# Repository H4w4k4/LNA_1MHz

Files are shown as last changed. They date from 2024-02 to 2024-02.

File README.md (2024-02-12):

 # LNA_1MHz
10Hz to 1MHz Low Noise Amplifier based on Linear Technology AN-159.

<p align="center">

 &nbsp; &nbsp;


</p>

# Design
The design is based on [Linear Technology AN-159 document](https://www.analog.com/en/resources/app-notes/an-159.html#author). It describe how to build a +80dB 10Hz to 1MHz low noise amplifier in order to measure noise level in the 2nV/√Hz range.

Following changes have been done:
+ Design re-routed in KiCad 7.0 to fit nicely into a Hammond 1590BBS housing
+ Selectable +60dB or +80dB gain
+ Full BW output removed

# Measure
A 60dB attenuator is placed on the input of the LNA to measure the frequency response. An Analog Discovery 3 is used as a network analyser.

<p align="center">

</p>

# Building it
The complete production files are available. The PCB is a 4-layer 102 x 82.6mm and every components is hand solderable. The LNA is powered by 6x AA batteries, consumption is about 100mA. Use the Gerber "housing_Lid_Drill" for drilling the holes in the housing cover. 

Total BOM cost is ~160USD + PCB + shipping.

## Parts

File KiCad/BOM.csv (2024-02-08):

Reference | Value | Footprint | Datasheet | Part | Qté
C1-C3, C6-C11, C13 | 68uF 20V | Capacitor_Tantalum_SMD:CP_EIA-7343-30_AVX-N_Pad2.25x2.55mm_HandSolder | ~ | AVX, TPSE686M020R0150 | 10
C4, C5 | 4u7F 50V | Capacitor_THT:C_Rect_L7.2mm_W7.2mm_P5.00mm_FKS2_FKP2_MKS2_MKP2 | ~ | WIMA, MKS2B044701K00K | 2
C12 | 150pF | Capacitor_SMD:C_1206_3216Metric_Pad1.33x1.80mm_HandSolder | ~ | AVX, 12065A151JAT2A | 1
C14 | 120pF | Capacitor_SMD:C_1206_3216Metric_Pad1.33x1.80mm_HandSolder | ~ | AVX, 12065A121JAT2A | 1
C15-C17, C19-C22, C24, C25, C28, C29, C32-C34 | 100uF 6V3 | Capacitor_SMD:C_1206_3216Metric_Pad1.33x1.80mm_HandSolder | ~ | MURATA, GRM31CR60J107ME39L | 14
C18, C39, C44, C49, C54 | 22pF | Capacitor_SMD:C_1206_3216Metric_Pad1.33x1.80mm_HandSolder | ~ | AVX, 12065A220JAT2A | 5
C23 | 100pF | Capacitor_SMD:C_1206_3216Metric_Pad1.33x1.80mm_HandSolder | ~ | AVX, 12065A101JAT2A | 1
C26 | 1500pF | Capacitor_SMD:C_1206_3216Metric_Pad1.33x1.80mm_HandSolder | ~ | AVX, 12065A152JAT2A | 1
C27 | 1200pF | Capacitor_SMD:C_1206_3216Metric_Pad1.33x1.80mm_HandSolder | ~ | AVX, 12065A122JAT2A | 1
C30 | 220pF | Capacitor_SMD:C_1206_3216Metric_Pad1.33x1.80mm_HandSolder | ~ | AVX, 12065A221JAT2A | 1
C31 | 1000pF | Capacitor_SMD:C_1206_3216Metric_Pad1.33x1.80mm_HandSolder | ~ | AVX, 12065A102JAT2A | 1
C35-C38, C42, C43, C47, C48, C52, C53, C57, C58 | 1uF | Capacitor_THT:C_Rect_L7.2mm_W5.5mm_P5.00mm_FKS2_FKP2_MKS2_MKP2 | ~ | WIMA, MKS2C041001F00K | 12
C40, C45, C50, C55 | 330uF 6V3 | Capacitor_Tantalum_SMD:CP_EIA-7343-30_AVX-N_Pad2.25x2.55mm_HandSolder | ~ | AVX, TPSD337M006R0100 | 4
C41, C46, C51, C56 | 300pF | Capacitor_SMD:C_0805_2012Metric_Pad1.18x1.45mm_HandSolder | ~ | AVX, 08053C301JAT2A | 4
C59, C60 | 180uF 25V | Capacitor_THT:CP_Radial_D8.0mm_P3.50mm | ~ | PANASONIC, 25SEPF180M | 2
H1-H6 | ~ | TestPoint:TestPoint_THTPad_2.0x2.0mm_Drill1.0mm | ~ |  | 6
J1-J3 | Conn_Coaxial | User_footprint:BNC_TycoElect_5227 | ~ | -- valeurs mixtées -- | 3
M1 | Hammond_1590BBS | User_footprint:Hammond_1590BBS |  | Hammond, 1590BBS | 1
M2, M3 | Battery_3x_AA | User_footprint:Battery_Holder_3x_AA_no_pin |  | Multicomp, MP000331 | 2
M4 | Switch DPDT | User_footprint:Multicomp, 1MD1T1B5M1QE |  | Multicomp, 1MD1T1B5M1QE | 1
M5 | Switch SPDT | User_footprint:Multicomp, 1MS1T1B5M1QE |  | Multicomp, 1MS1T1B5M1QE | 1
R1 | 1k5 | Resistor_SMD:R_1206_3216Metric_Pad1.30x1.75mm_HandSolder | ~ | VISHAY, CRCW12061K50FKEA | 1
R2 | 511 | Resistor_SMD:R_1206_3216Metric_Pad1.30x1.75mm_HandSolder | ~ | VISHAY, CRCW1206511RFKEA | 1
R3, R5-R7, R9, R10 | 100 | Resistor_SMD:R_1206_3216Metric_Pad1.30x1.75mm_HandSolder | ~ | VISHAY, CRCW1206100RFKEA | 6
R4 | 2k | Resistor_SMD:R_1206_3216Metric_Pad1.30x1.75mm_HandSolder | ~ | VISHAY, CRCW12062K00FKEA | 1
R8 | 5k76 | Resistor_SMD:R_1206_3216Metric_Pad1.30x1.75mm_HandSolder | ~ | VISHAY, CRCW12065K76FKEA | 1
R11 | 499 | Resistor_SMD:R_1206_3216Metric_Pad1.30x1.75mm_HandSolder | ~ | VISHAY, CRCW1206499RFKEA | 1
R12, R17, R22, R23, R27, R28, R30, R31, R35, R36, R38, R39, R43, R44, R46, R47, R51, R52 | 4k02 | Resistor_SMD:R_1206_3216Metric_Pad1.30x1.75mm_HandSolder | ~ | VISHAY, CRCW12064K02FKEA | 18
R13, R18 | 2k15 | Resistor_SMD:R_1206_3216Metric_Pad1.30x1.75mm_HandSolder | ~ | VISHAY, CRCW12062K15FKEA | 2
R14, R19 | 1k69 | Resistor_SMD:R_1206_3216Metric_Pad1.30x1.75mm_HandSolder | ~ | VISHAY, CRCW12061K69FKEA | 2
R15, R20 | 1k24 | Resistor_SMD:R_1206_3216Metric_Pad1.30x1.75mm_HandSolder | ~ | VISHAY, CRCW12061K24FKEA | 2
R16, R21 | 49R9 | Resistor_SMD:R_1206_3216Metric_Pad1.30x1.75mm_HandSolder | ~ | VISHAY, CRCW120649R9FKEA | 2
R24, R25, R32, R33, R40, R41, R48, R49 | 499 | Resistor_SMD:R_0805_2012Metric_Pad1.20x1.40mm_HandSolder | ~ | VISHAY, CRCW0805499RFKEA | 8
R26, R34, R42, R50 | 249 | Resistor_SMD:R_1206_3216Metric_Pad1.30x1.75mm_HandSolder | ~ | YAGEO, RC1206FR-07249RL | 4
R29, R37, R45, R53 | 10 | Resistor_SMD:R_1206_3216Metric_Pad1.30x1.75mm_HandSolder | ~ | VISHAY, CRCW120610R0FKEAC | 4
RV1 | 1k | Potentiometer_THT:Potentiometer_Bourns_3296X_Horizontal | ~ | BOURNS, 3296X-1-102LF | 1
RV2 | 200 | Potentiometer_THT:Potentiometer_Bourns_3296X_Horizontal | ~ | BOURNS, 3296X-1-201LF | 1
U1 | LT6232CGN | Package_SO:SSOP-16_3.9x4.9mm_P0.635mm | https://www.analog.com/media/en/technical-documentation/data-sheets/623012fc.pdf | Linear Tech., LT6232CGN#PBF | 1
U2 | LT1365CS | Package_SO:SO-16_3.9x9.9mm_P1.27mm | https://www.analog.com/media/en/technical-documentation/data-sheets/13645fa.pdf | Linear Tech., LT1365CS#PBF | 1
U3, U5, U7, U9 | LT1818CS8 | Package_SO:SO-8_3.9x4.9mm_P1.27mm | https://www.analog.com/media/en/technical-documentation/data-sheets/18189fb.pdf | Linear Tech., LT1818CS8#PBF | 4
U4, U6, U8, U10 | THAT300S14-U | Package_SO:SOIC-14_3.9x8.7mm_P1.27mm |  | THAT Corporation, THAT300S14-U | 4

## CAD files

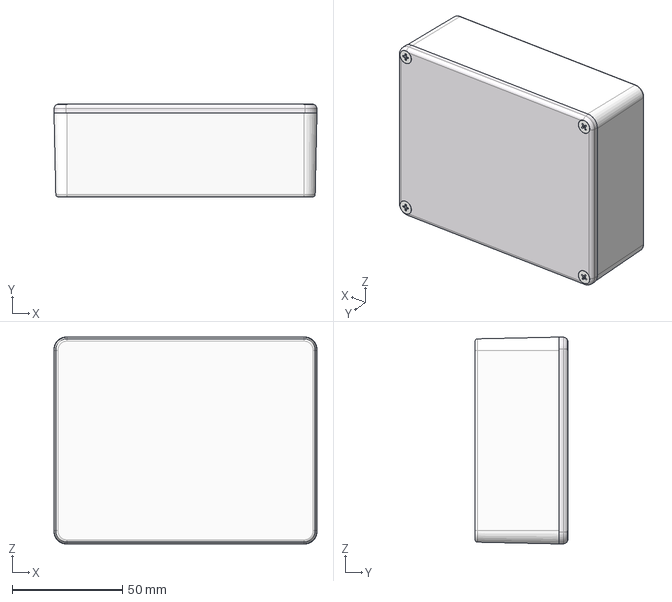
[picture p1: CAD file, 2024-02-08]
Datasheet/1590BBS.stp
119.5 x 42.1 x 94.0 mm
1590BBS BOX
1590C LID

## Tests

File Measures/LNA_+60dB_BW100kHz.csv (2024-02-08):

#Digilent WaveForms Network Analyzer - Bode
#Device Name: Discovery3
#Date Time: 2024-02-08 18:55:14.613
#Start: 1 Hz
#Stop: 2e+06 Hz
#Steps: 151
#Wavegen: Wavegen C1
#Amplification: 1 X
#Settle: 10 ms
#MinPeriods: 32
#Channel: Channel 2
#Range: 5.13569 V
#Offset: 8.29643e-05 V
#Relative: yes
Frequency (Hz) | Channel 2 Magnitude (dB) | Channel 2 Phase (deg)
1.000000000000002 | -69.21915246975358 | -10.53627862849748
1.101556726136675 | -65.77347539883461 | -15.40823207395555
1.213427220896945 | -62.46739881671027 | -19.32897107968216
1.336658916856357 | -59.15304754669258 | -24.49056377111295
1.472405620413677 | -55.86433923501731 | -29.5831362070994
1.621938314768127 | -52.57366210205483 | -34.94621980450103
1.786657060011607 | -49.28892850285725 | -40.45000866842491
1.968104101755354 | -46.04095129571814 | -46.43900398095219
2.167978311025786 | -42.79188704663309 | -52.81104147129451
2.388151090628878 | -39.58508847265773 | -59.62683612144482
2.630683896912867 | -36.40459607019136 | -66.90852757420174
2.897847540983796 | -33.26233210588731 | -74.70068064957806
3.192143450089312 | -30.18728147217772 | -82.99532355520429
3.516327088239006 | -27.19509883693937 | -91.79747261116199
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

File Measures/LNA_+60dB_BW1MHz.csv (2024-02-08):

#Digilent WaveForms Network Analyzer - Bode
#Device Name: Discovery3
#Date Time: 2024-02-08 18:37:19.417
#Start: 1 Hz
#Stop: 2e+06 Hz
#Steps: 151
#Wavegen: Wavegen C1
#Amplification: 1 X
#Settle: 10 ms
#MinPeriods: 32
#Channel: Channel 2
#Range: 5.13569 V
#Offset: 8.29643e-05 V
#Relative: yes
Frequency (Hz) | Channel 2 Magnitude (dB) | Channel 2 Phase (deg)
1.000000000000002 | -69.04775908654929 | -10.72955637263085
1.101556726136675 | -65.82871182051774 | -15.40263981909862
1.213427220896945 | -62.47151987370549 | -20.08651417017764
1.336658916856357 | -59.13202901519229 | -24.67357037469868
1.472405620413677 | -55.85419452960114 | -29.75647817102871
1.621938314768127 | -52.56066100462618 | -35.11122578529563
1.786657060011607 | -49.27228953772921 | -40.69510331111118
1.968104101755354 | -45.9244819256 | -46.72983689252341
2.167978311025786 | -42.6936882901208 | -53.10627089097253
2.388151090628878 | -39.49241014424292 | -59.91638837230778
2.630683896912867 | -36.31540838655298 | -67.2299170460977
2.897847540983796 | -33.18452881246163 | -75.01662364643897
3.192143450089312 | -30.11804440064484 | -83.31408385802631
3.516327088239006 | -27.13069815361774 | -92.11605199372303
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

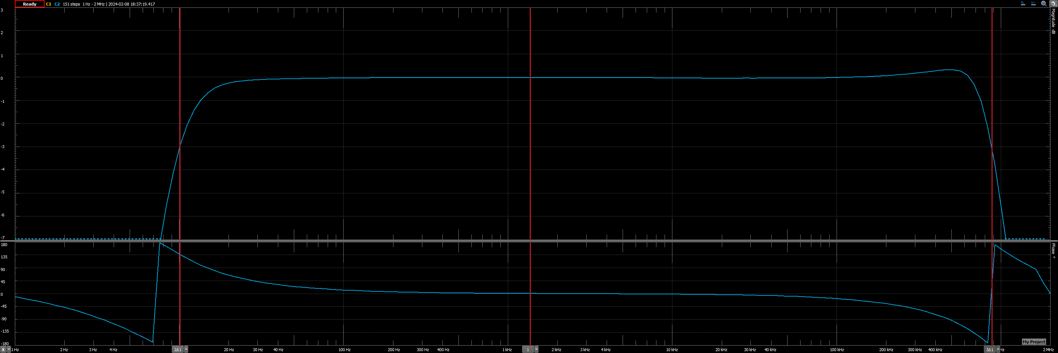
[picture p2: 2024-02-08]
Measures/LNA_+60dB_BW1MHz.png

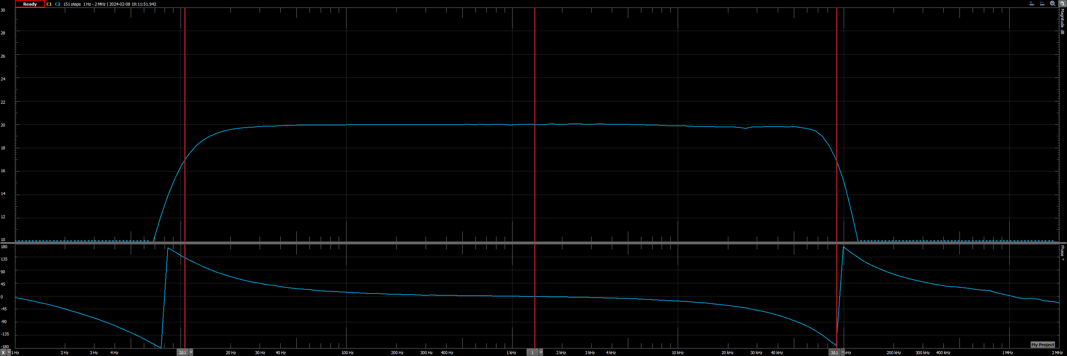
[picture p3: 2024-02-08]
Measures/LNA_+80dB_BW100kHz.png

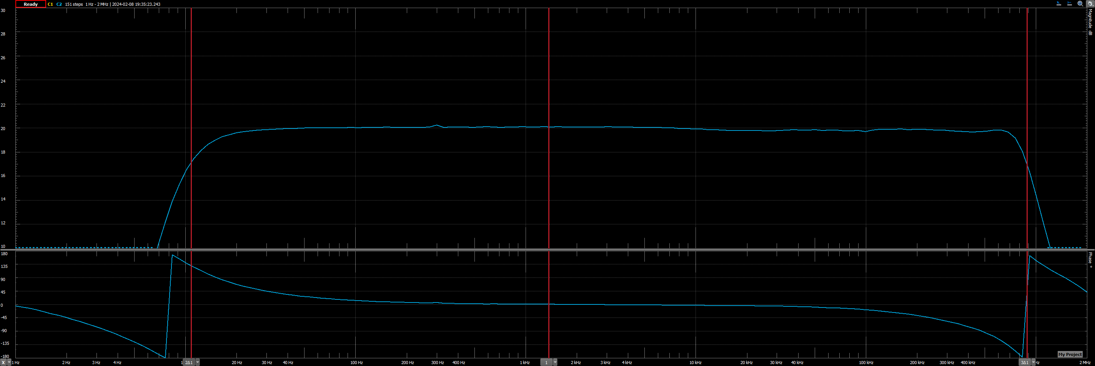
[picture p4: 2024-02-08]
Measures/LNA_+80dB_BW1MHz.png

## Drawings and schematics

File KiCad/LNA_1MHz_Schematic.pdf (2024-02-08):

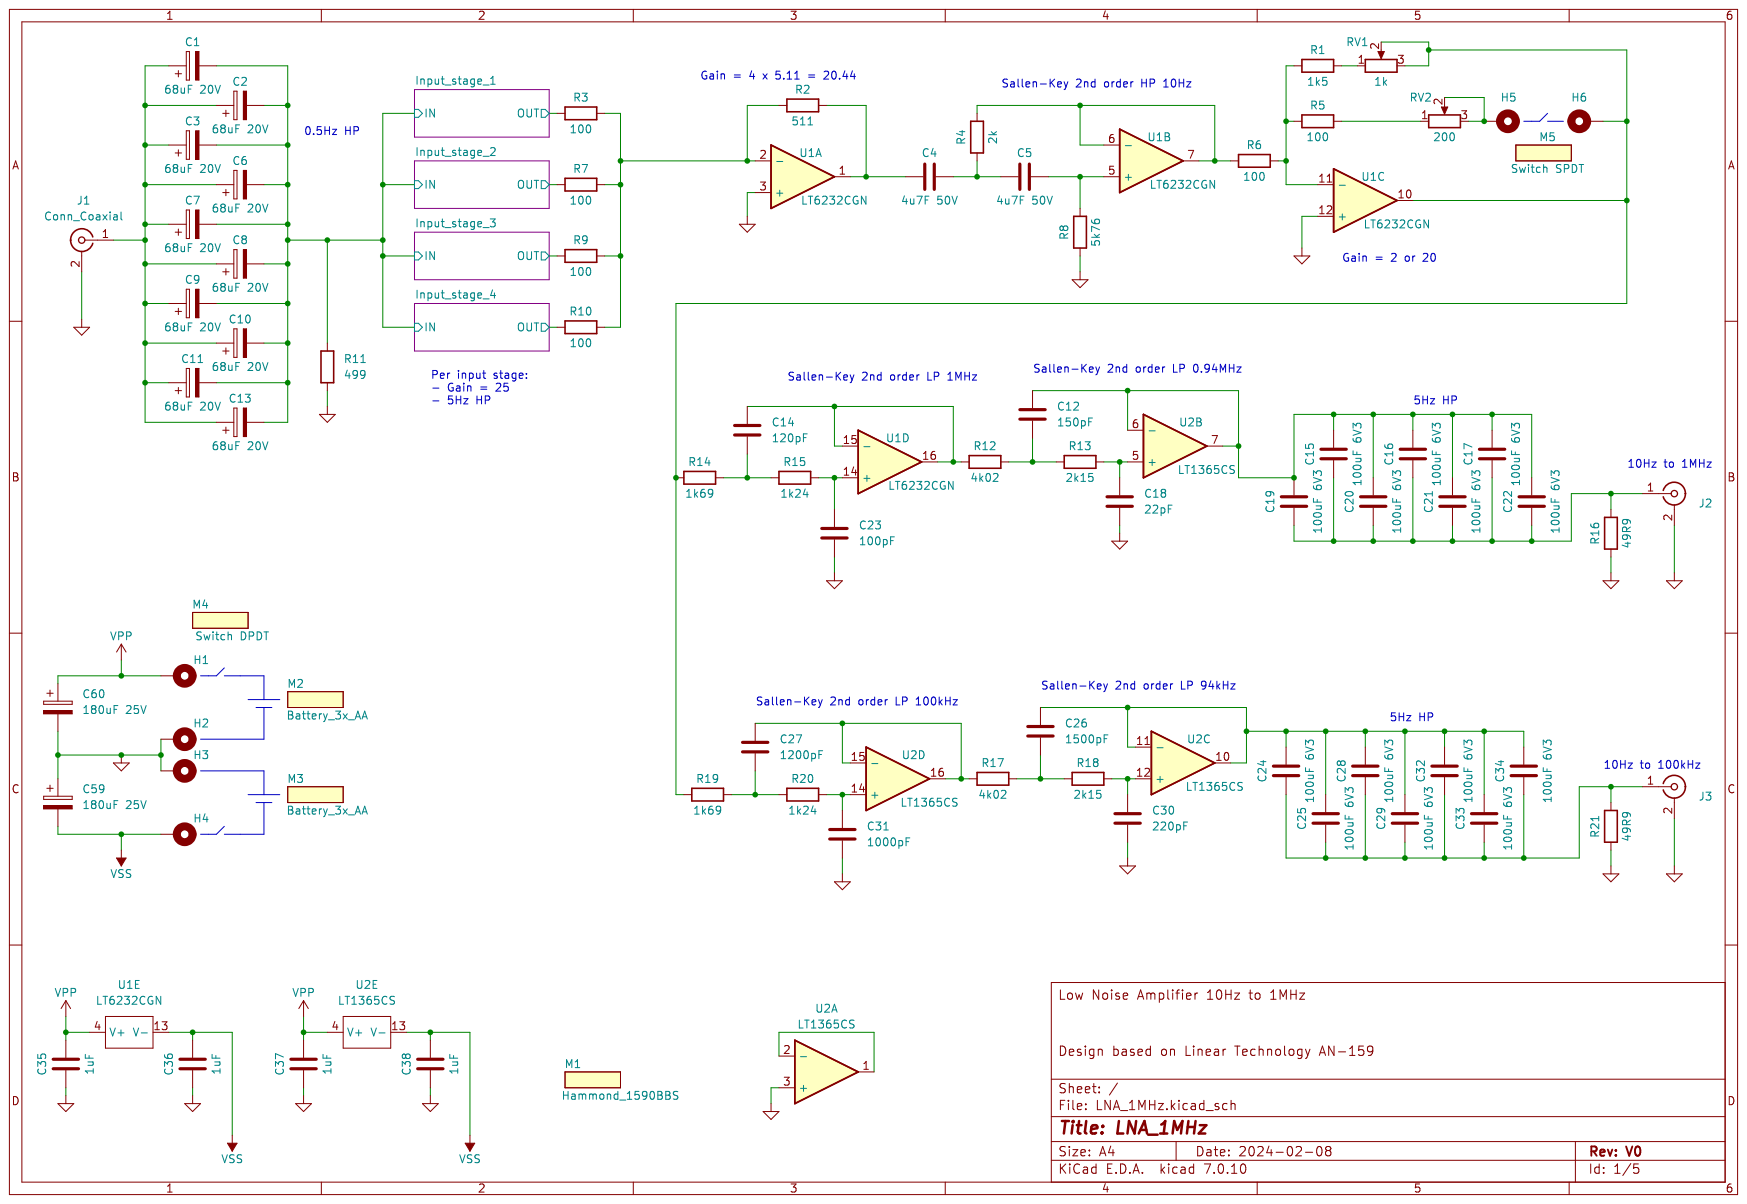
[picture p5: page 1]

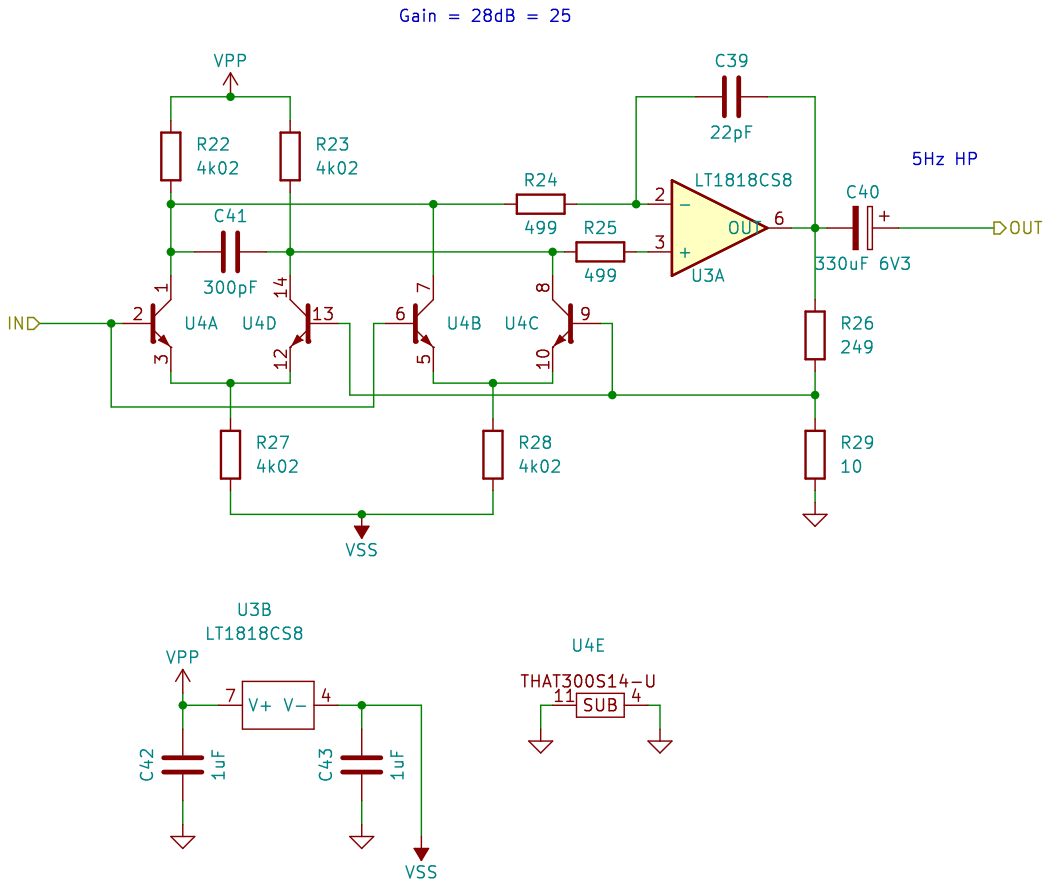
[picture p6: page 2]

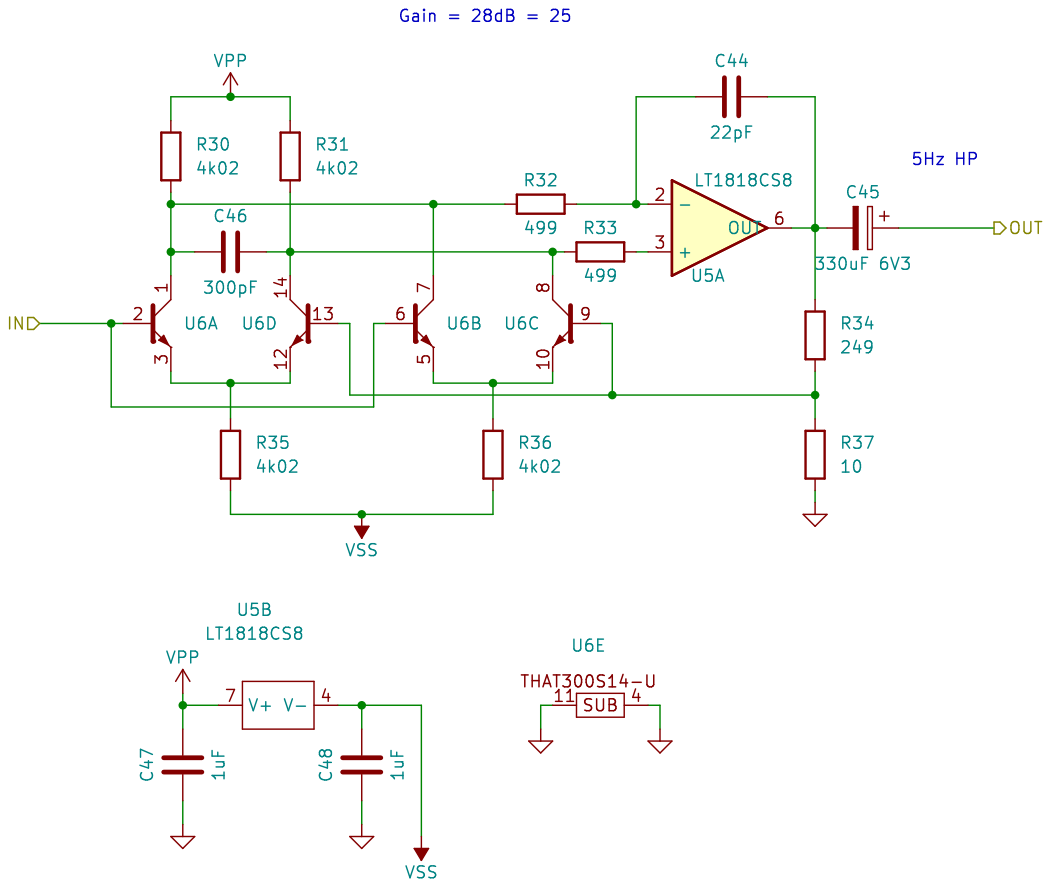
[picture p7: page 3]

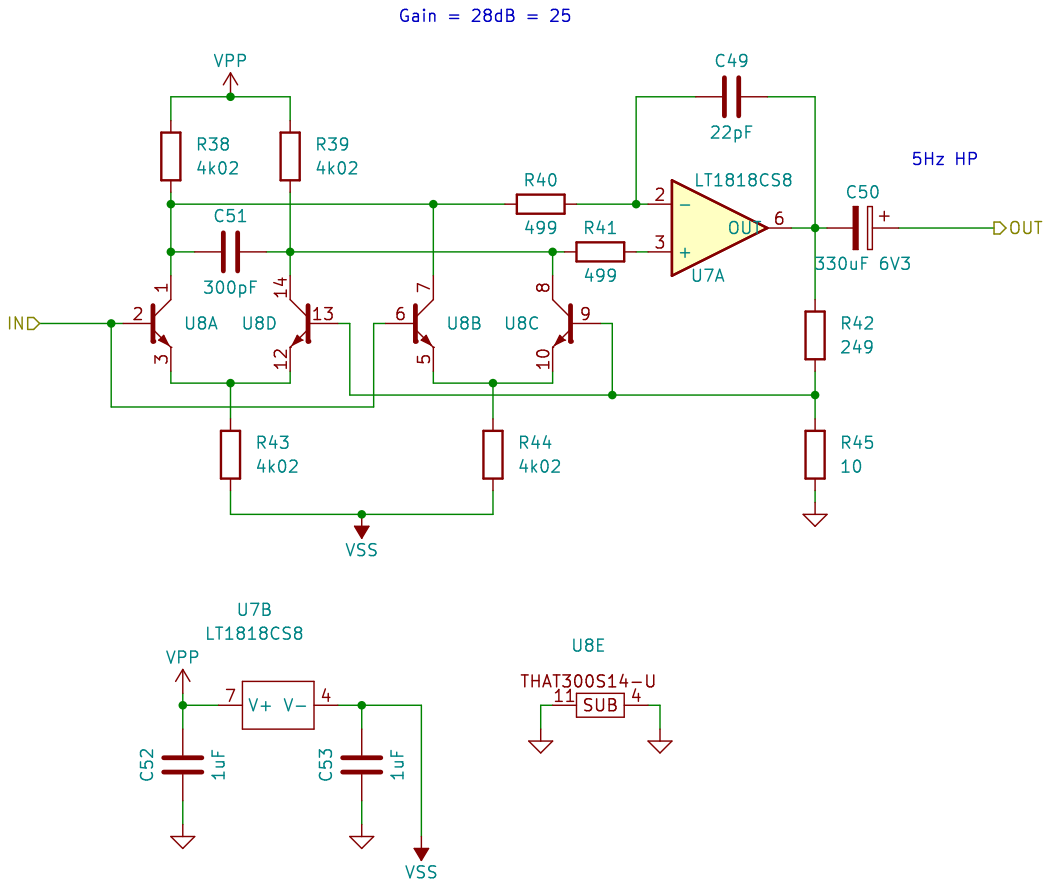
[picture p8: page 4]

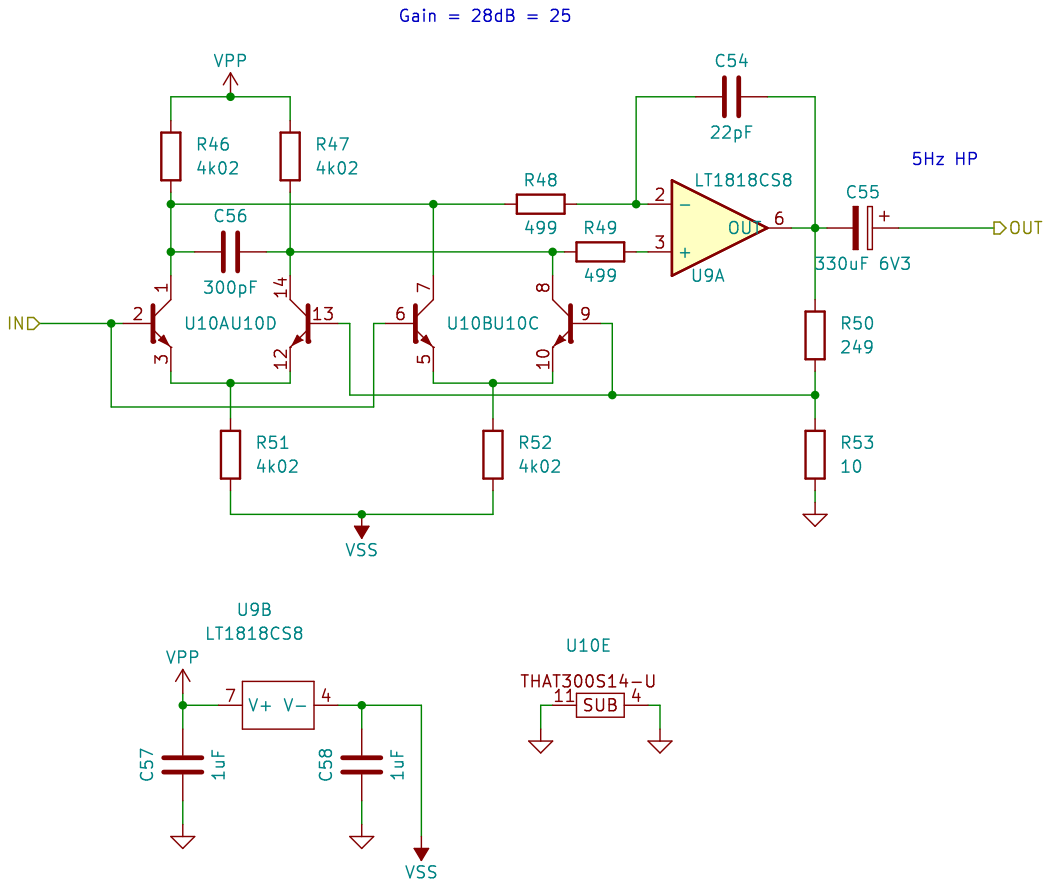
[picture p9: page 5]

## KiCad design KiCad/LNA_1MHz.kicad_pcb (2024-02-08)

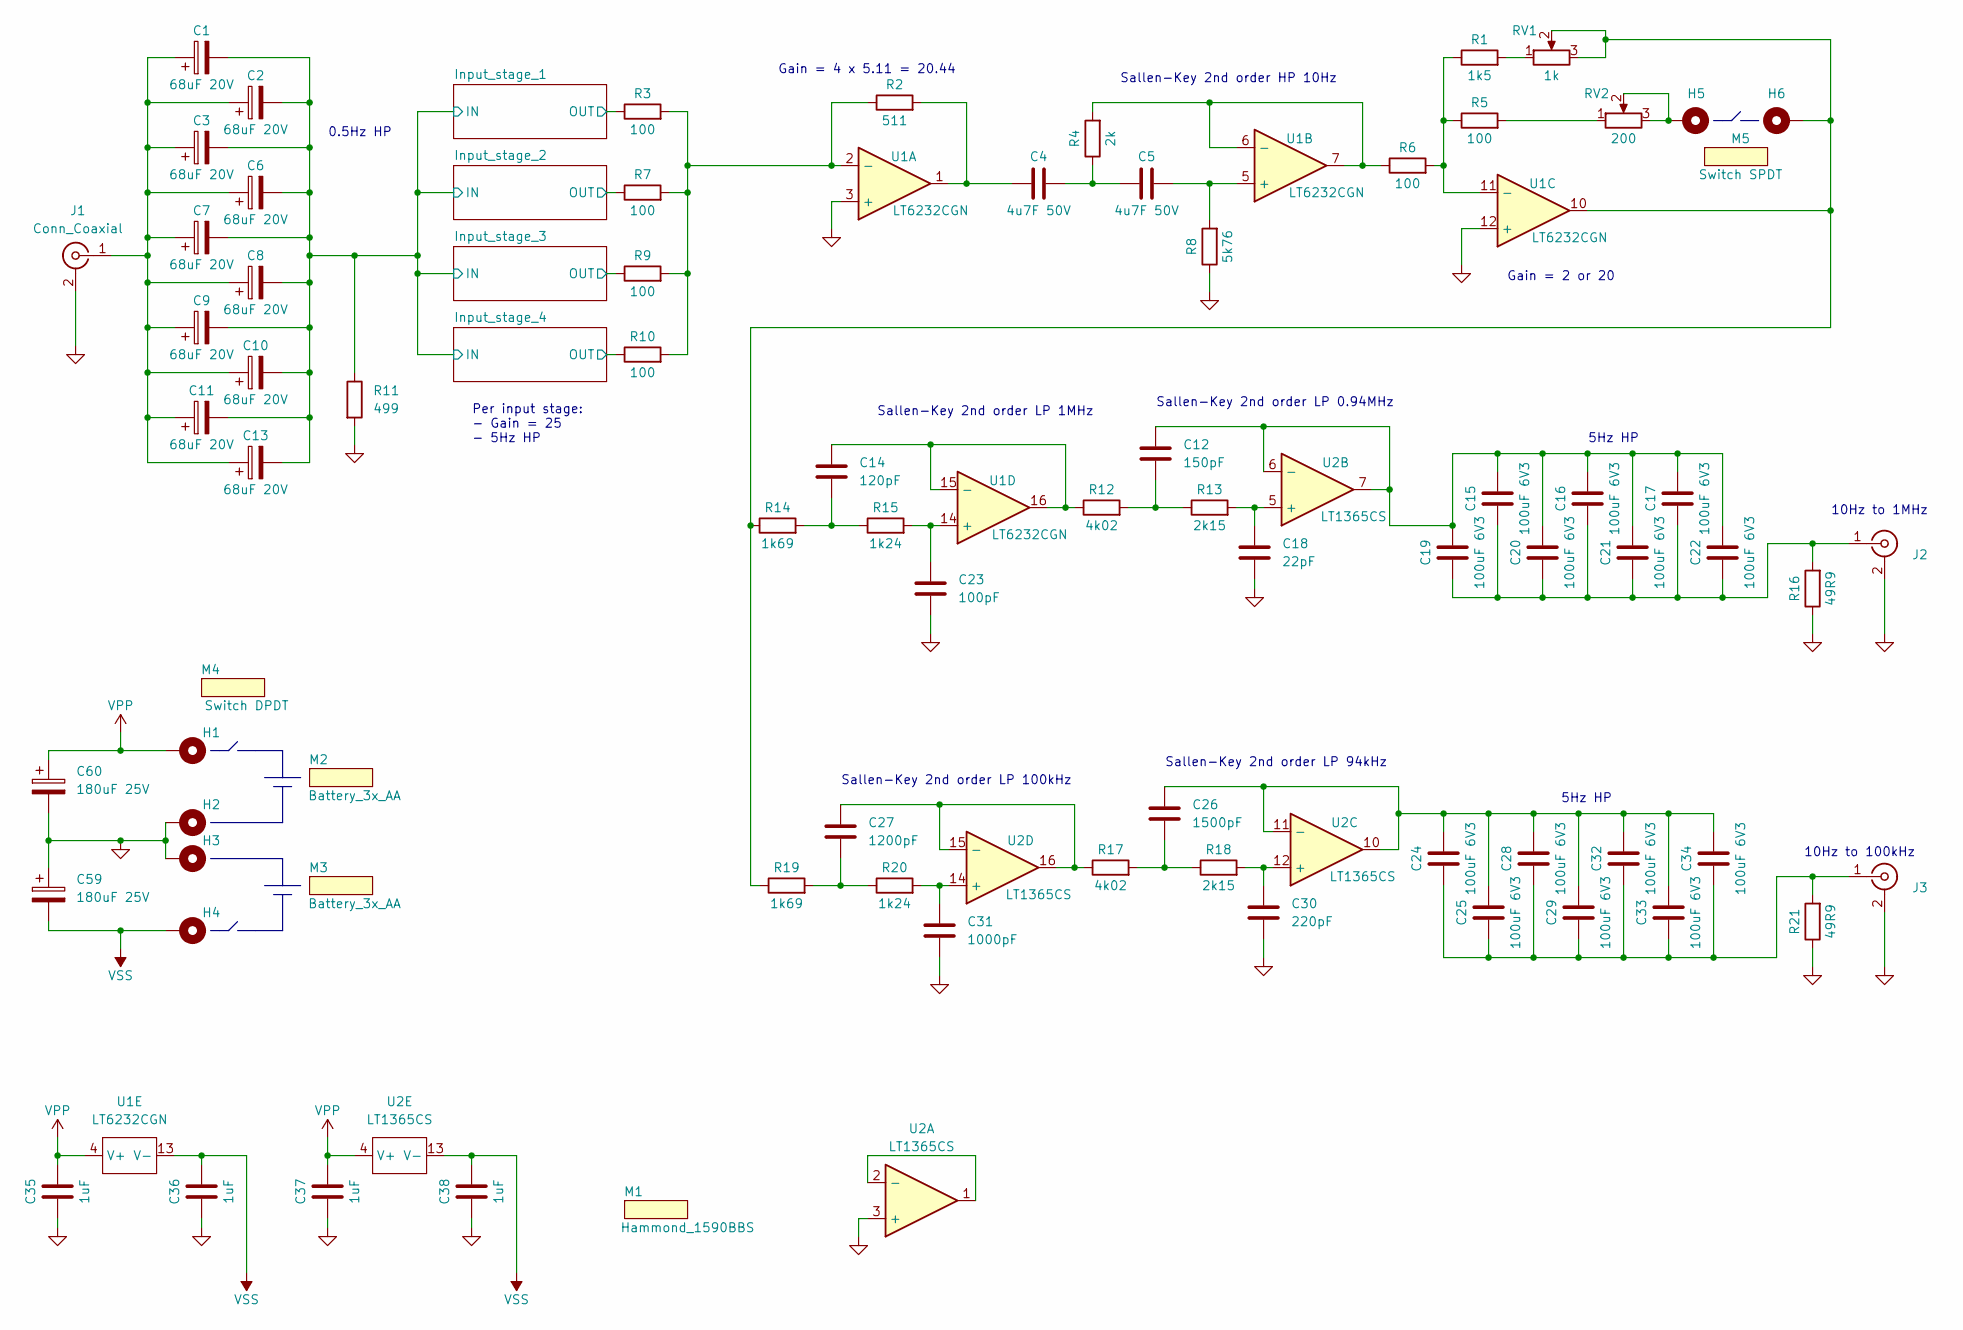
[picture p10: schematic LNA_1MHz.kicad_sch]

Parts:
C1, C2, C3, C6, C7, C8, C9, C10, C11, C13: 68uF 20V; CP_EIA-7343-30_AVX-N_Pad2.25x2.55mm_HandSolder; Part AVX, TPSE686M020R0150
C4, C5: 4u7F 50V; C_Rect_L7.2mm_W7.2mm_P5.00mm_FKS2_FKP2_MKS2_MKP2; Part WIMA, MKS2B044701K00K
C12: 150pF; C_1206_3216Metric_Pad1.33x1.80mm_HandSolder; Part AVX, 12065A151JAT2A
C14: 120pF; C_1206_3216Metric_Pad1.33x1.80mm_HandSolder; Part AVX, 12065A121JAT2A
C15, C16, C17, C19, C20, C21, C22, C24, C25, C28, C29, C32, C33, C34: 100uF 6V3; C_1206_3216Metric_Pad1.33x1.80mm_HandSolder; Part MURATA, GRM31CR60J107ME39L
C18: 22pF; C_1206_3216Metric_Pad1.33x1.80mm_HandSolder; Part AVX, 12065A220JAT2A
C23: 100pF; C_1206_3216Metric_Pad1.33x1.80mm_HandSolder; Part AVX, 12065A101JAT2A
C26: 1500pF; C_1206_3216Metric_Pad1.33x1.80mm_HandSolder; Part AVX, 12065A152JAT2A
C27: 1200pF; C_1206_3216Metric_Pad1.33x1.80mm_HandSolder; Part AVX, 12065A122JAT2A
C30: 220pF; C_1206_3216Metric_Pad1.33x1.80mm_HandSolder; Part AVX, 12065A221JAT2A
C31: 1000pF; C_1206_3216Metric_Pad1.33x1.80mm_HandSolder; Part AVX, 12065A102JAT2A
C35, C36, C37, C38: 1uF; C_Rect_L7.2mm_W5.5mm_P5.00mm_FKS2_FKP2_MKS2_MKP2; Part WIMA, MKS2C041001F00K
C59, C60: 180uF 25V; CP_Radial_D8.0mm_P3.50mm; Part PANASONIC, 25SEPF180M
H1, H2, H3, H4, H5, H6: TestPoint_THTPad_2.0x2.0mm_Drill1.0mm
J1: Conn_Coaxial; BNC_TycoElect_5227; Part TE 5227673­1, TE 1­329632­2, TE 1­32963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
J2, J3: Conn_Coaxial; BNC_TycoElect_5227; Part TE 5227222-3, TE 1­329632­2, TE 1­32963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
M1: Hammond_1590BBS; Part Hammond, 1590BBS
M2, M3: Battery_3x_AA; Battery_Holder_3x_AA_no_pin; Part Multicomp, MP000331
M4: Switch DPDT; Multicomp, 1MD1T1B5M1QE; Part Multicomp, 1MD1T1B5M1QE
M5: Switch SPDT; Multicomp, 1MS1T1B5M1QE; Part Multicomp, 1MS1T1B5M1QE
R1: 1k5; R_1206_3216Metric_Pad1.30x1.75mm_HandSolder; Part VISHAY, CRCW12061K50FKEA
R2: 511; R_1206_3216Metric_Pad1.30x1.75mm_HandSolder; Part VISHAY, CRCW1206511RFKEA
R3, R5, R6, R7, R9, R10: 100; R_1206_3216Metric_Pad1.30x1.75mm_HandSolder; Part VISHAY, CRCW1206100RFKEA
R4: 2k; R_1206_3216Metric_Pad1.30x1.75mm_HandSolder; Part VISHAY, CRCW12062K00FKEA
R8: 5k76; R_1206_3216Metric_Pad1.30x1.75mm_HandSolder; Part VISHAY, CRCW12065K76FKEA
R11: 499; R_1206_3216Metric_Pad1.30x1.75mm_HandSolder; Part VISHAY, CRCW1206499RFKEA
R12, R17: 4k02; R_1206_3216Metric_Pad1.30x1.75mm_HandSolder; Part VISHAY, CRCW12064K02FKEA
R13, R18: 2k15; R_1206_3216Metric_Pad1.30x1.75mm_HandSolder; Part VISHAY, CRCW12062K15FKEA
R14, R19: 1k69; R_1206_3216Metric_Pad1.30x1.75mm_HandSolder; Part VISHAY, CRCW12061K69FKEA
R15, R20: 1k24; R_1206_3216Metric_Pad1.30x1.75mm_HandSolder; Part VISHAY, CRCW12061K24FKEA
R16, R21: 49R9; R_1206_3216Metric_Pad1.30x1.75mm_HandSolder; Part VISHAY, CRCW120649R9FKEA
RV1: 1k; Potentiometer_Bourns_3296X_Horizontal; Part BOURNS, 3296X-1-102LF
RV2: 200; Potentiometer_Bourns_3296X_Horizontal; Part BOURNS, 3296X-1-201LF
U1: LT6232CGN; SSOP-16_3.9x4.9mm_P0.635mm; Part Linear Tech., LT6232CGN#PBF
U2: LT1365CS; SO-16_3.9x9.9mm_P1.27mm; Part Linear Tech., LT1365CS#PBF

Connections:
/Input_stage_1/IN: C1.2, C2.2, C3.2, C6.2, C7.2, C8.2, C9.2, C10.2, C11.2, C13.2, R11.1; also elsewhere on the board
/Input_stage_1/OUT: R3.1; also elsewhere on the board
/Input_stage_2/OUT: R7.1; also elsewhere on the board
/Input_stage_3/OUT: R9.1; also elsewhere on the board
/Input_stage_4/OUT: R10.1; also elsewhere on the board
GND: C18.2, C23.2, C30.2, C31.2, C35.1, C36.1, C37.1, C38.1, C59.1, C60.2, H2.1, H3.1, J1.2 (Ext), J2.2 (Ext), J3.2 (Ext), R8.1, R11.2, R16.1, R21.1, U1.3 (+), U1.12 (+), U2.3 (+); also elsewhere on the board
unnamed: C4.1, R2.2, U1.1
unnamed: C4.2, C5.1, R4.1
unnamed: C12.2, R12.2, R13.1
unnamed: C14.2, R14.2, R15.1
unnamed: C26.2, R17.2, R18.1
unnamed: C27.2, R19.2, R20.1
unnamed: H5.1, RV2.2, RV2.3
unnamed: H6.1, R14.1, R19.1, RV1.2, RV1.3, U1.10
unnamed: C1.1, C2.1, C3.1, C6.1, C7.1, C8.1, C9.1, C10.1, C11.1, C13.1, J1.1 (In)
unnamed: C15.1, C16.1, C17.1, C19.1, C20.1, C21.1, C22.1, J2.1 (In), R16.2
unnamed: C24.2, C25.2, C28.2, C29.2, C32.2, C33.2, C34.2, J3.1 (In), R21.2
unnamed: R1.2, RV1.1
unnamed: R5.2, RV2.1
unnamed: R2.1, R3.2, R7.2, R9.2, R10.2, U1.2 (-)
unnamed: C5.2, R8.2, U1.5 (+)
unnamed: R4.2, R6.1, U1.6 (-), U1.7
unnamed: R1.1, R5.1, R6.2, U1.11 (-)
unnamed: C23.1, R15.2, U1.14 (+)
unnamed: C14.1, R12.1, U1.15 (-), U1.16
unnamed: U2.1, U2.2 (-)
unnamed: C18.1, R13.2, U2.5 (+)
unnamed: C12.1, C15.2, C16.2, C17.2, C19.2, C20.2, C21.2, C22.2, U2.6 (-), U2.7
unnamed: C30.1, R18.2, U2.12 (+)
unnamed: C24.1, C25.1, C26.1, C28.1, C29.1, C32.1, C33.1, C34.1, U2.10, U2.11 (-)
unnamed: C31.1, R20.2, U2.14 (+)
unnamed: C27.1, R17.1, U2.15 (-), U2.16
VPP: C35.2, C37.2, C60.1, H1.1, U1.4 (V+), U2.4 (V+); also elsewhere on the board
VSS: C36.2, C38.2, C59.2, H4.1, U1.13 (V-), U2.13 (V-); also elsewhere on the board

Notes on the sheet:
10Hz to 1MHz
Sallen-Key 2nd order LP 1MHz
Sallen-Key 2nd order LP 94kHz
Sallen-Key 2nd order LP 100kHz
Sallen-Key 2nd order HP 10Hz
5Hz HP
0.5Hz HP
Gain = 2 or 20
10Hz to 100kHz
Gain = 4 x 5.11 = 20.44
Per input stage: - Gain = 25 - 5Hz HP
Sallen-Key 2nd order LP 0.94MHz

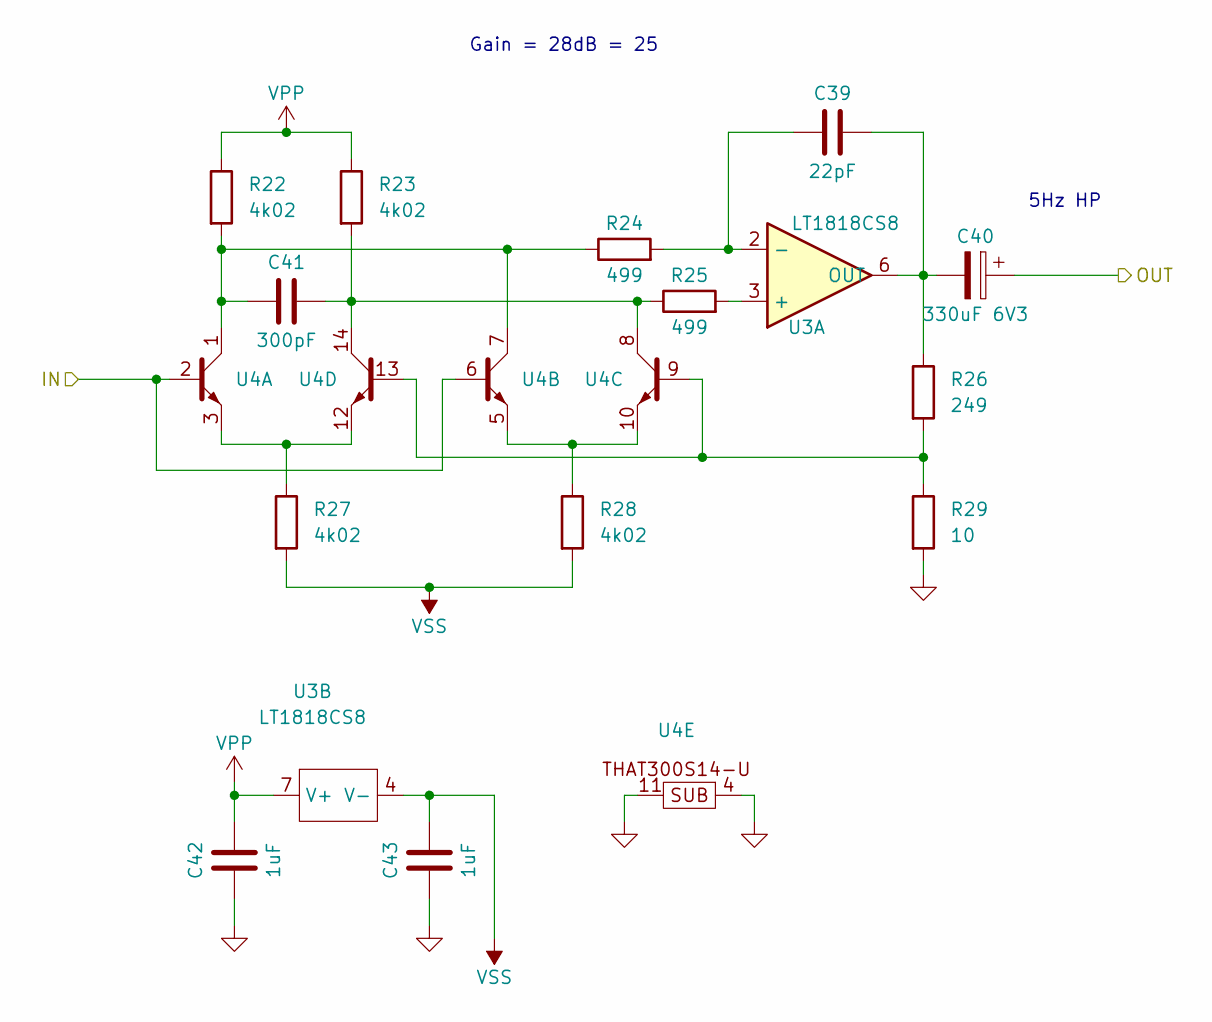
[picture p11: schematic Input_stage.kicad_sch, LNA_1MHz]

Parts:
C39: 22pF; C_1206_3216Metric_Pad1.33x1.80mm_HandSolder; Part AVX, 12065A220JAT2A
C40: 330uF 6V3; CP_EIA-7343-30_AVX-N_Pad2.25x2.55mm_HandSolder; Part AVX, TPSD337M006R0100
C41: 300pF; C_0805_2012Metric_Pad1.18x1.45mm_HandSolder; Part AVX, 08053C301JAT2A
C42, C43: 1uF; C_Rect_L7.2mm_W5.5mm_P5.00mm_FKS2_FKP2_MKS2_MKP2; Part WIMA, MKS2C041001F00K
R22, R23, R27, R28: 4k02; R_1206_3216Metric_Pad1.30x1.75mm_HandSolder; Part VISHAY, CRCW12064K02FKEA
R24, R25: 499; R_0805_2012Metric_Pad1.20x1.40mm_HandSolder; Part VISHAY, CRCW0805499RFKEA
R26: 249; R_1206_3216Metric_Pad1.30x1.75mm_HandSolder; Part YAGEO, RC1206FR-07249RL
R29: 10; R_1206_3216Metric_Pad1.30x1.75mm_HandSolder; Part VISHAY, CRCW120610R0FKEAC
U3: LT1818CS8; SO-8_3.9x4.9mm_P1.27mm; Part Linear Tech., LT1818CS8#PBF
U4: THAT300S14-U; SOIC-14_3.9x8.7mm_P1.27mm; Part THAT Corporation, THAT300S14-U

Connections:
/Input_stage_1/IN: U4.2 (B), U4.6 (B); also elsewhere on the board
/Input_stage_1/OUT: C40.1; also elsewhere on the board
GND: C42.1, C43.1, R29.2, U4.4 (SUB), U4.11 (SUB); also elsewhere on the board
unnamed: R25.2, U3.3 (+)
unnamed: C39.1, R24.2, U3.2 (-)
unnamed: C39.2, C40.2, R26.1, U3.6 (OUT)
unnamed: C41.1, R22.2, R24.1, U4.1 (C), U4.7 (C)
unnamed: R27.1, U4.3 (E), U4.12 (E)
unnamed: R28.1, U4.5 (E), U4.10 (E)
unnamed: R26.2, R29.1, U4.9 (B), U4.13 (B)
unnamed: C41.2, R23.2, R25.1, U4.8 (C), U4.14 (C)
VPP: C42.2, R22.1, R23.1, U3.7 (V+); also elsewhere on the board
VSS: C43.2, R27.2, R28.2, U3.4 (V-); also elsewhere on the board

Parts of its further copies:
C44, C49, C54: 22pF; C_1206_3216Metric_Pad1.33x1.80mm_HandSolder; Part AVX, 12065A220JAT2A
C45, C50, C55: 330uF 6V3; CP_EIA-7343-30_AVX-N_Pad2.25x2.55mm_HandSolder; Part AVX, TPSD337M006R0100
C46, C51, C56: 300pF; C_0805_2012Metric_Pad1.18x1.45mm_HandSolder; Part AVX, 08053C301JAT2A
C47, C48, C52, C53, C57, C58: 1uF; C_Rect_L7.2mm_W5.5mm_P5.00mm_FKS2_FKP2_MKS2_MKP2; Part WIMA, MKS2C041001F00K
R30, R31, R35, R36, R38, R39, R43, R44, R46, R47, R51, R52: 4k02; R_1206_3216Metric_Pad1.30x1.75mm_HandSolder; Part VISHAY, CRCW12064K02FKEA
R32, R33, R40, R41, R48, R49: 499; R_0805_2012Metric_Pad1.20x1.40mm_HandSolder; Part VISHAY, CRCW0805499RFKEA
R34, R42, R50: 249; R_1206_3216Metric_Pad1.30x1.75mm_HandSolder; Part YAGEO, RC1206FR-07249RL
R37, R45, R53: 10; R_1206_3216Metric_Pad1.30x1.75mm_HandSolder; Part VISHAY, CRCW120610R0FKEAC
U5, U7, U9: LT1818CS8; SO-8_3.9x4.9mm_P1.27mm; Part Linear Tech., LT1818CS8#PBF
U6, U8, U10: THAT300S14-U; SOIC-14_3.9x8.7mm_P1.27mm; Part THAT Corporation, THAT300S14-U

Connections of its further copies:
/Input_stage_1/IN: U6.2 (B), U6.6 (B), U8.2 (B), U8.6 (B), U10.2 (B), U10.6 (B); also elsewhere on the board
/Input_stage_2/OUT: C45.1; also elsewhere on the board
/Input_stage_3/OUT: C50.1; also elsewhere on the board
/Input_stage_4/OUT: C55.1; also elsewhere on the board
GND: C47.1, C48.1, C52.1, C53.1, C57.1, C58.1, R37.2, R45.2, R53.2, U6.4 (SUB), U6.11 (SUB), U8.4 (SUB), U8.11 (SUB), U10.4 (SUB), U10.11 (SUB); also elsewhere on the board
unnamed: R33.2, U5.3 (+)
unnamed: C44.1, R32.2, U5.2 (-)
unnamed: C44.2, C45.2, R34.1, U5.6 (OUT)
unnamed: C46.1, R30.2, R32.1, U6.1 (C), U6.7 (C)
unnamed: R35.1, U6.3 (E), U6.12 (E)
unnamed: R36.1, U6.5 (E), U6.10 (E)
unnamed: R34.2, R37.1, U6.9 (B), U6.13 (B)
unnamed: C46.2, R31.2, R33.1, U6.8 (C), U6.14 (C)
unnamed: R41.2, U7.3 (+)
unnamed: C49.1, R40.2, U7.2 (-)
unnamed: C49.2, C50.2, R42.1, U7.6 (OUT)
unnamed: C51.1, R38.2, R40.1, U8.1 (C), U8.7 (C)
unnamed: R43.1, U8.3 (E), U8.12 (E)
unnamed: R44.1, U8.5 (E), U8.10 (E)
unnamed: R42.2, R45.1, U8.9 (B), U8.13 (B)
unnamed: C51.2, R39.2, R41.1, U8.8 (C), U8.14 (C)
unnamed: R49.2, U9.3 (+)
unnamed: C54.1, R48.2, U9.2 (-)
unnamed: C54.2, C55.2, R50.1, U9.6 (OUT)
unnamed: C56.1, R46.2, R48.1, U10.1 (C), U10.7 (C)
unnamed: R51.1, U10.3 (E), U10.12 (E)
unnamed: R52.1, U10.5 (E), U10.10 (E)
unnamed: R50.2, R53.1, U10.9 (B), U10.13 (B)
unnamed: C56.2, R47.2, R49.1, U10.8 (C), U10.14 (C)
VPP: C47.2, C52.2, C57.2, R30.1, R31.1, R38.1, R39.1, R46.1, R47.1, U5.7 (V+), U7.7 (V+), U9.7 (V+); also elsewhere on the board
VSS: C48.2, C53.2, C58.2, R35.2, R36.2, R43.2, R44.2, R51.2, R52.2, U5.4 (V-), U7.4 (V-), U9.4 (V-); also elsewhere on the board

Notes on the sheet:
5Hz HP
Gain = 28dB = 25

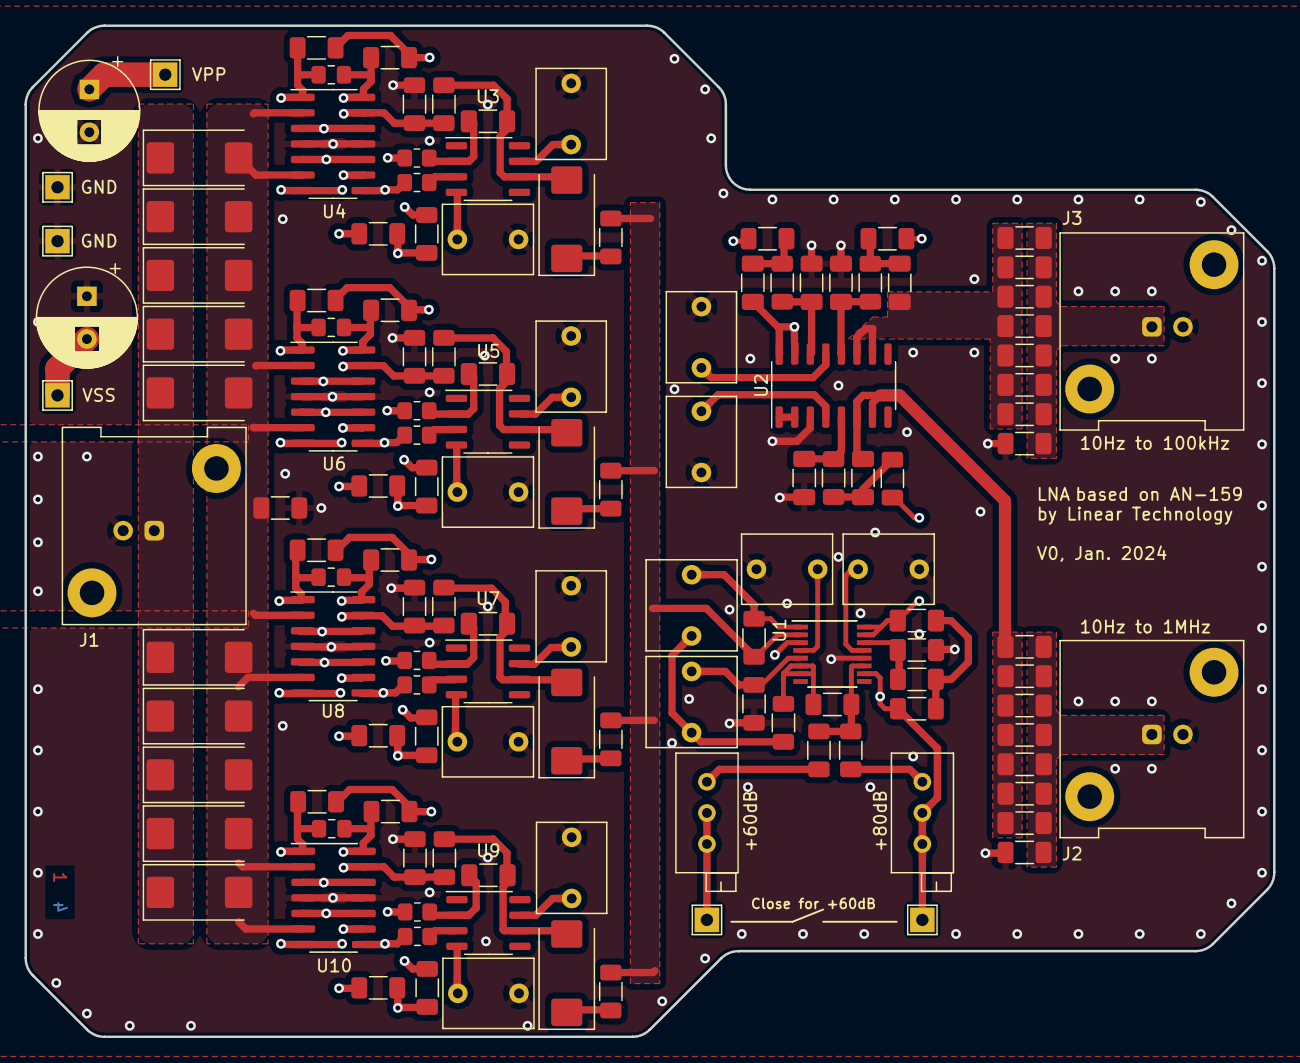
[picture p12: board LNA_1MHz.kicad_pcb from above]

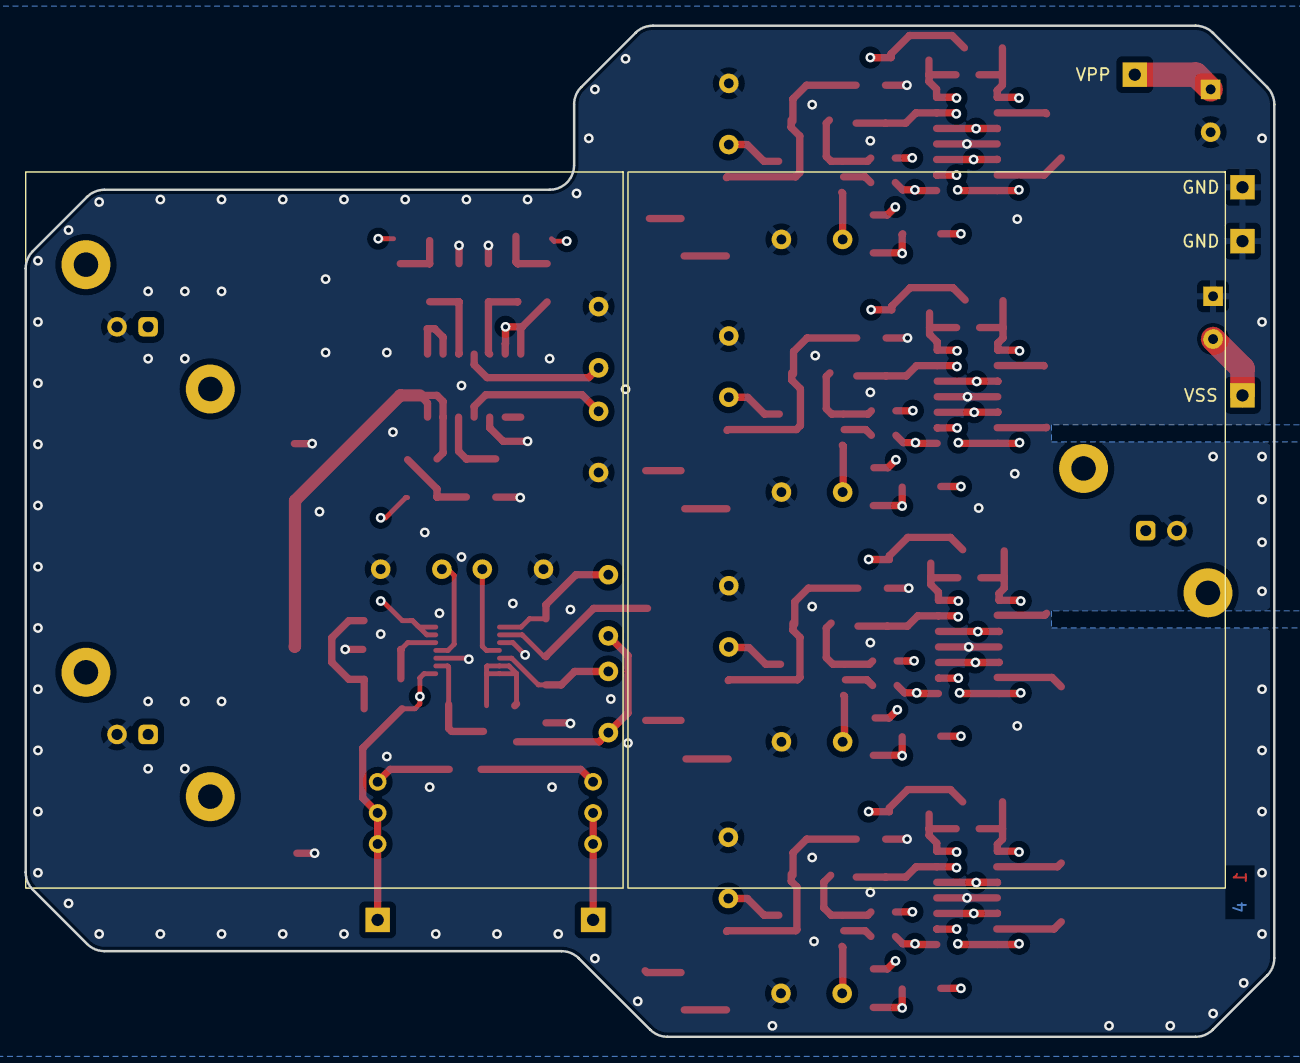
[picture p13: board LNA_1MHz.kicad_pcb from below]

Board: 4 copper layers, 102.0 x 82.6 mm, 139 parts (2 on the bottom side), 66 nets.
